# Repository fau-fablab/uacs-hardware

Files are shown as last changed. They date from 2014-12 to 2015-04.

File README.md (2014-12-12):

uacs
====

An universal access control system.

Usecase(s)
----------

* machine access control system:
  * monitor access to the machine
  * monitor the machine use time and whether the machine is in use or not
  * add the possibility to reserve machines
  * add a dead man's switch to the machine (force the user to interact with the uacs terminal every x minutes)

Features
--------

* [2.8" Touchscreen](../v2.0/pcb/datasheets/ILI9341.pdf)
* [ISO/IEC 14443A/MIFARE Reader/Writer (supports e.g. MIFARE Classic + DESFire)](../v2.0/pcb/datasheets/PN532-short.pdf)
* [ethernet-access](../v2.0/pcb/datasheets/W5100.pdf)
* powered via 2.1mm DC-Jack (Voltage: 7-50V) or passive POE (power over ethernet)
* micro-sd-card reader to store data (lcd-background images, caching of authorized rfid cards, ..)
* multiple IOs (I²C, UART, SPI, digital/analog pins e.g. to control relais or get sensor values)
* (piezo-)speaker for audio feedback
* real time clock

Remark
------

Development is still in progress, this is not a final version!<br />
If you want to contribute, take a look at the [wiki](https://github.com/fau-fablab/uacs/wiki/Contribution).

PCB
---

The terminal is built from two stacked pcbs in order to save space.<br />
Eagle Layout files and datasheets of used components can be found under [/pcb](../v2.0/pcb).

Firmware
--------

The firmware is written in arduino (c/c++) since the pcb is arduino mega compatible.<br />
The backend is (not yet ;)) written in Python.<br />
All code can be found under [/firmware](../v2.0/firmware).

License
-------

<br />This work is licensed under a <a rel="license" href="http://creativecommons.org/licenses/by-sa/4.0/">Creative Commons Attribution-ShareAlike 4.0 International License</a>.

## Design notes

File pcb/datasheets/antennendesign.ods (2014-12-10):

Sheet: Sheet1
Messen:
Lant = | 1.2 | uH | Q = | 35
Rant = | 1.6 | Ohm | Rges = | 2.92 | Rext = | 0.7 | Ohm
C1a = C1b = | 28 | pF |  | 200
C2a = C2b = | 202

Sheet: Sheet2
Messen:
L = | 1.25 | uH
R = | 2.4 | uH
La = Lb = | 0.625 | uH | Q = | 35
Rcoil = | 1.2 | Ohm | RL = | 3.04 |  | Rext = | 0.3 | Ohm
Xc1 = | 658 | Ohm |  | a | +jb
C1a = C1b = | 18 | pF | Z = | 200 | 0 | Xl = | 53.2499954783
Xc2 = | 58 | Ohm | w = | 85.20 | 1/us
C2a = C2b = | 204.0 | pF
 |  |  |  |  | a = | 15.7706926779
 |  |  |  |  |  | 53.5714240225
 |  |  |  |  | Nenner = | 19.8669443621

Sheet: Directly matched antenna
 | Directly matched antenna design |  |  |  |  |  | 06.11.2001 RBt
Input:
L = | 0.63 | uH | Q = | 22 |  | Z = Zant = | 700 | Ohm | Input
R = | 3.77 | Ohm
La = Lb = | 0.315 | uH | RL = | 2.44 |  |  |  |  | Result
Rcoil = | 1.885 | Ohm | RL/2 = | 1.22 | Ohm
Result:
C2a = C2b = | 419.9 | pF |  |  |  | Rext = | -0.67 | Ohm
C1a = C1b = | 40.4 | pF

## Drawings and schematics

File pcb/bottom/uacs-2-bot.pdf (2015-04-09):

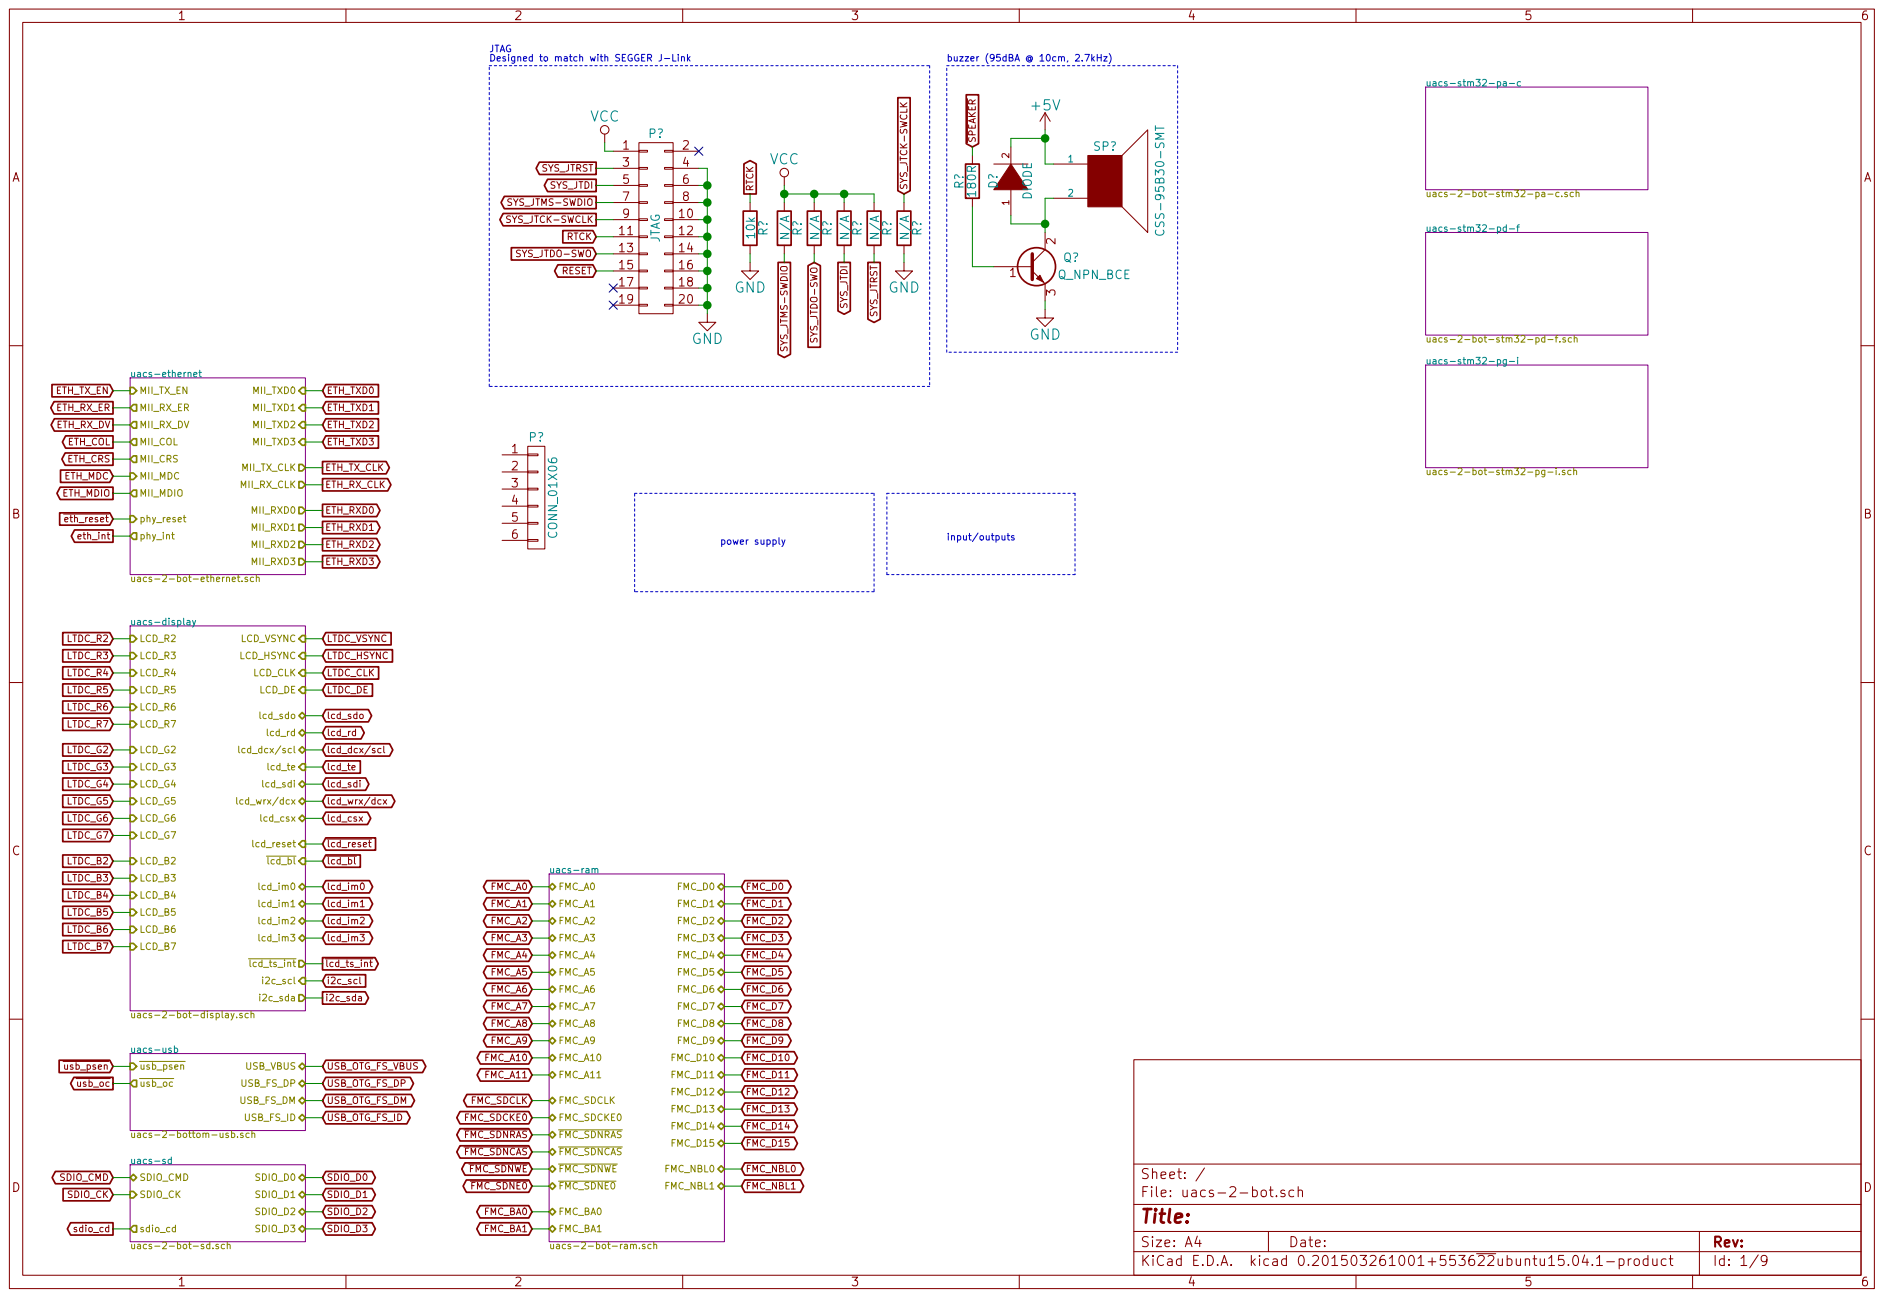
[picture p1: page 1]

uacs-stm32-pa-c uacs-2-bot-stm32-pa-c.sch

uacs-stm32-pd-f uacs-2-bot-stm32-pd-f.sch

uacs-stm32-pg-i uacs-2-bot-stm32-pg-i.sch

uacs-2-bottom-usb.sch

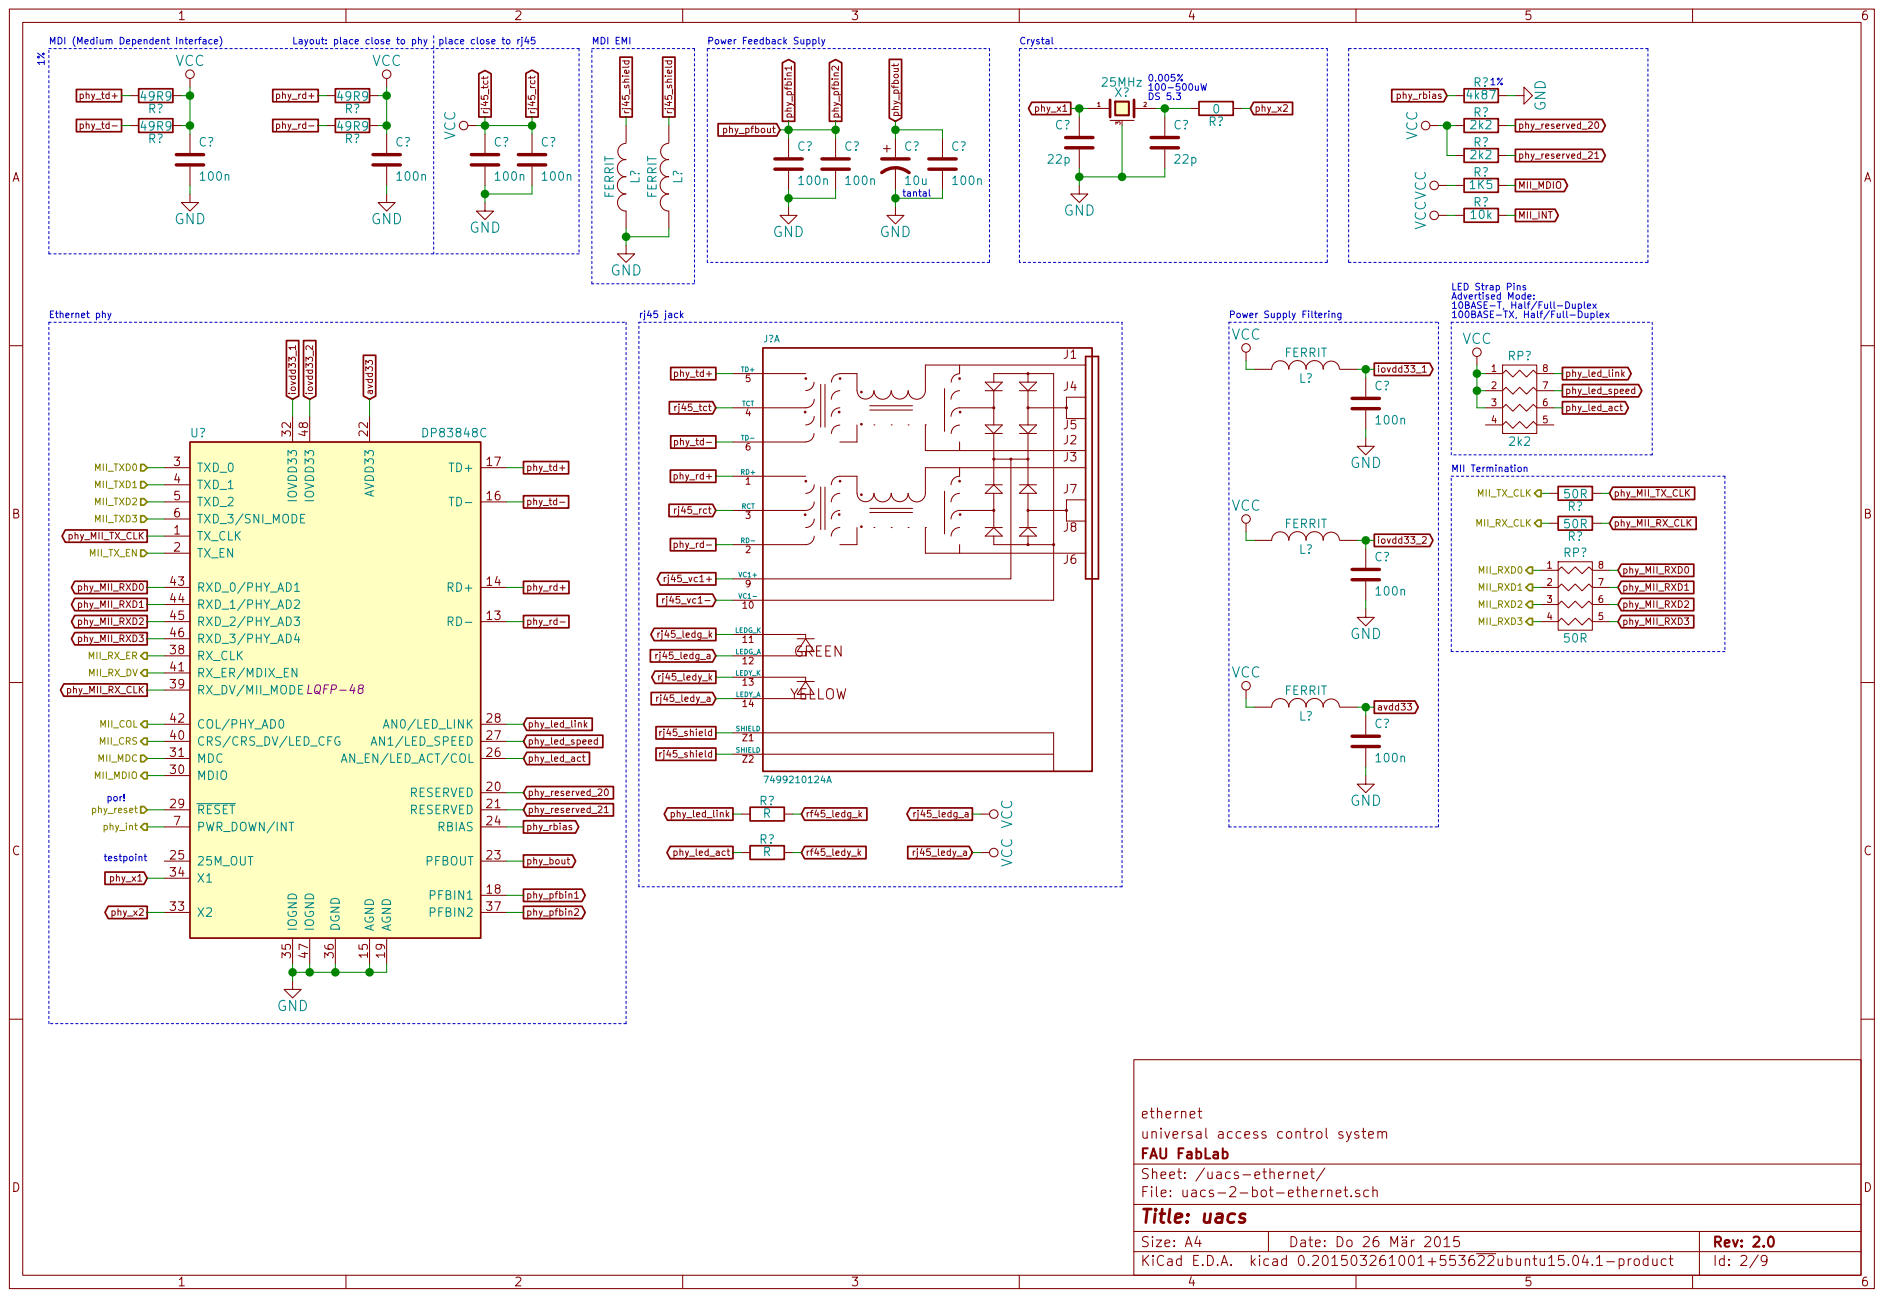
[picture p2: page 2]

LED Strap Pins Advertised Mode: 10BASE-T, Half/Full-Duplex 100BASE-TX, Half/Full-Duplex VCC VCC

ethernet
universal access control system
File: uacs-2-bot-ethernet.sch Sheet: /uacs-ethernet/ FAU FabLab

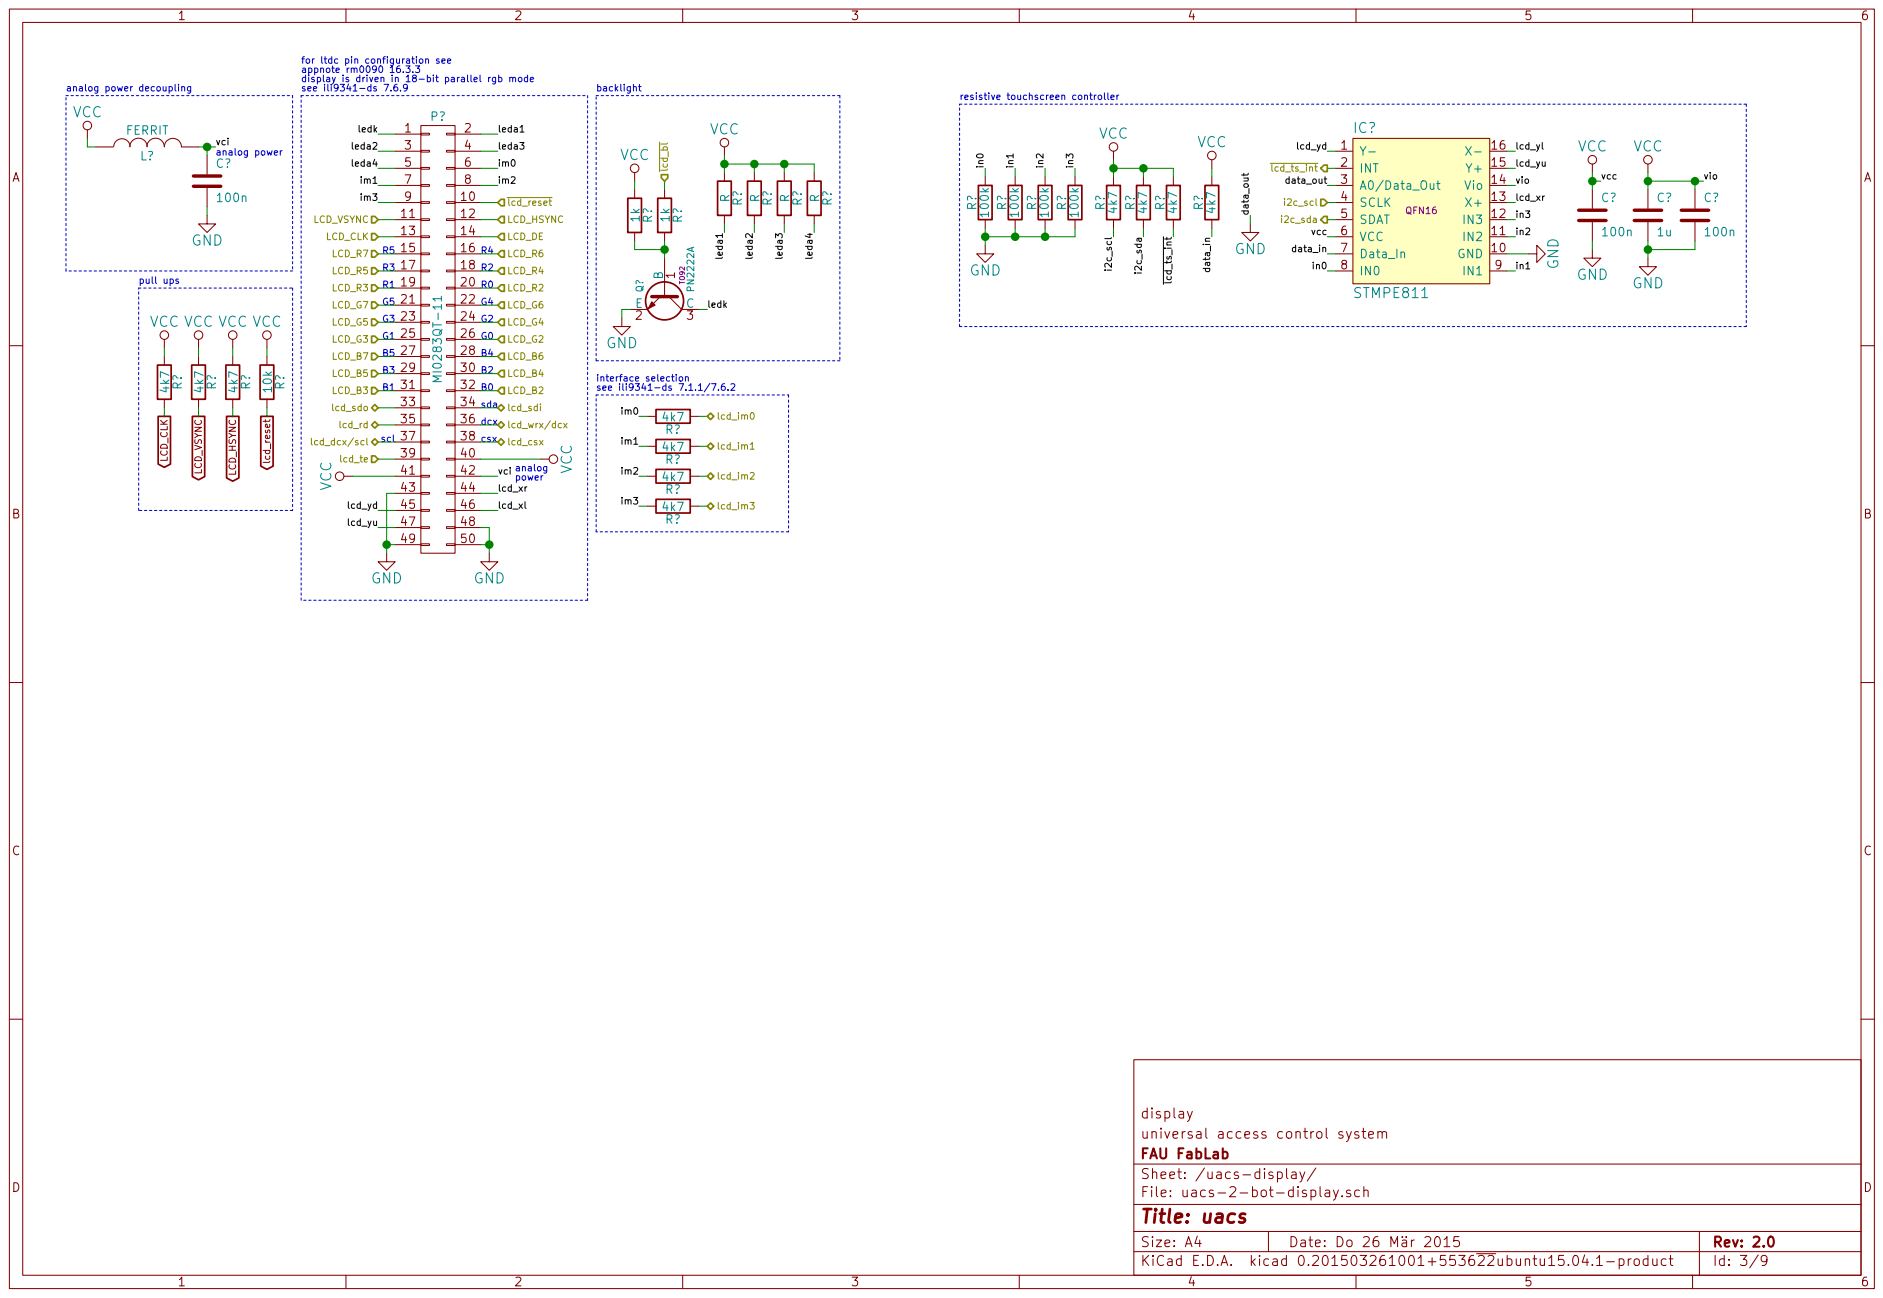
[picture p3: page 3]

for ltdc pin configuration see
appnote rm0090 16.3.3
display is driven in 18-bit parallel rgb mode

analog power pull ups analog power decoupling
100n VCC

display
universal access control system
Sheet: /uacs-display/ FAU FabLab

File: uacs-2-bot-display.sch
Id: 3/9 Title: uacs

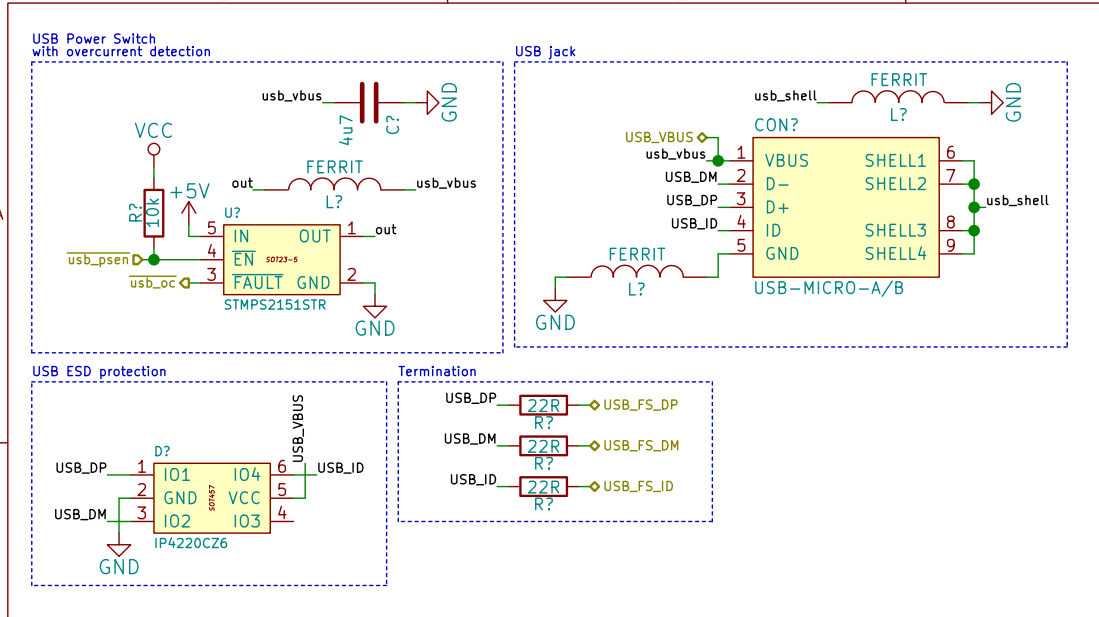
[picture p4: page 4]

Id: 4/9 Title: File: uacs-2-bottom-usb.sch Sheet: /uacs-usb/

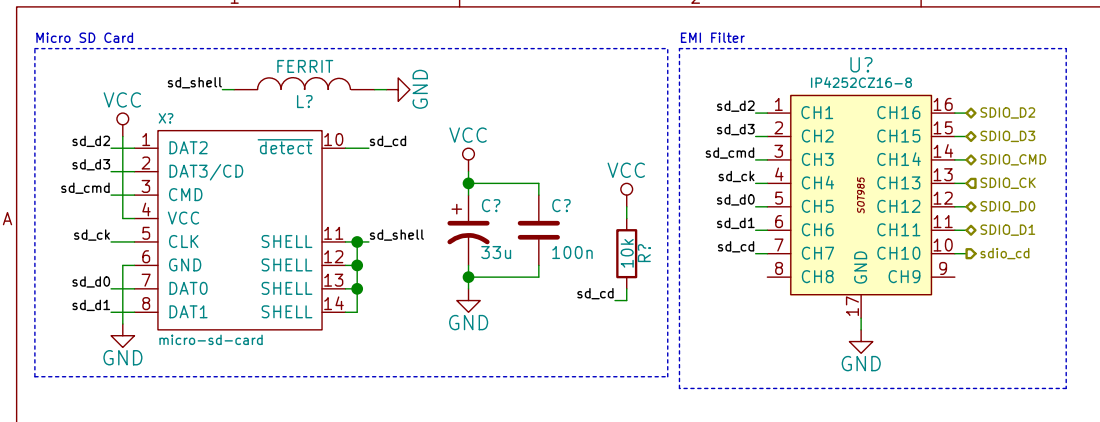
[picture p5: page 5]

Id: 5/9 Title: File: uacs-2-bot-sd.sch Sheet: /uacs-sd/

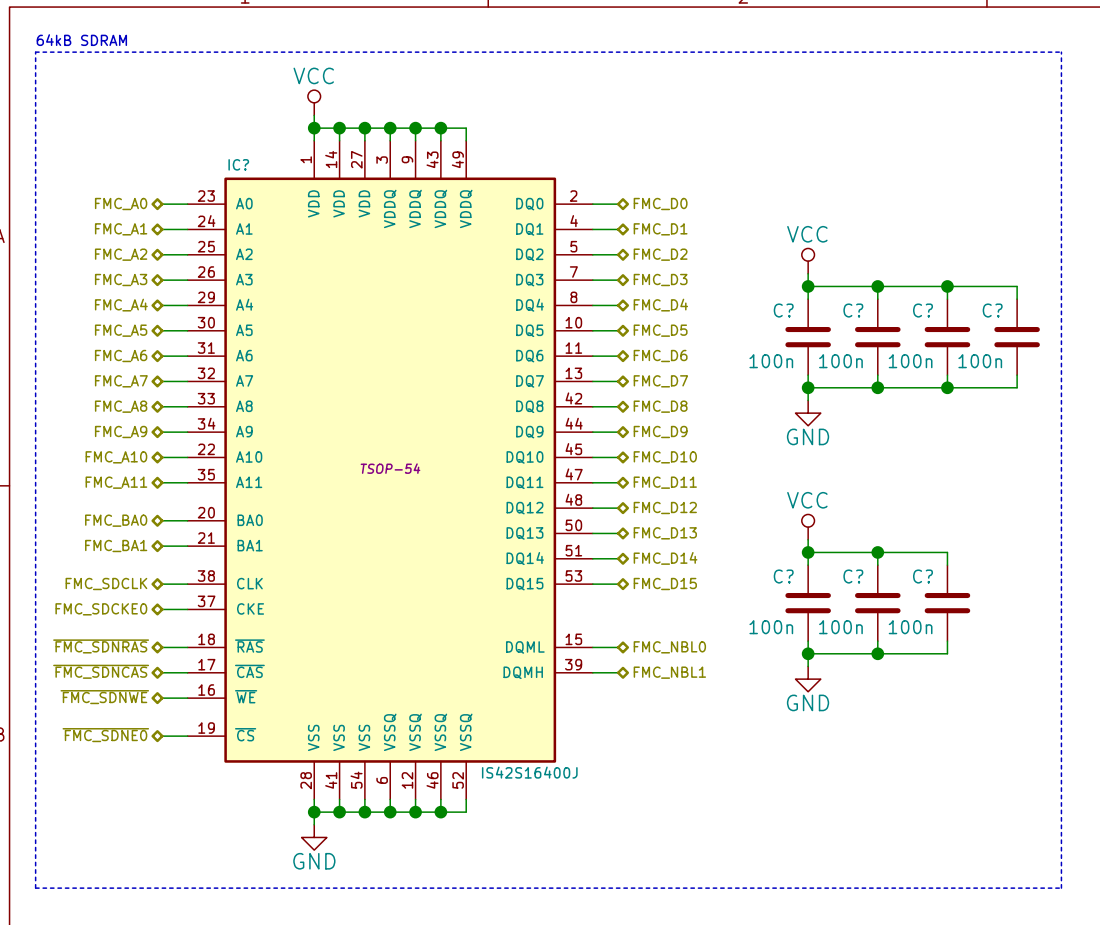
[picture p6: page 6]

9 DQ5 10 BA0 20 A5 30 DQ13 50 DQ6 11 BA1 21 A6 31 VSS 41 DQ14 51 VSSQ 12 A10 22 A7 32 DQ8 42 VSSQ 52 DQ7 13 A0 23 A8 33 VDDQ 43 DQ15 53 VDD 14 A1 24 A9 34 DQ9 44 VSS 54 DQML 15 A2 25 A11 35 DQ10 45 WE 16 A3 26 VSSQ 46 CAS 17 VDD 27 CKE 37 DQ11 47 RAS 18 VSS 28 CLK 38 DQ12 48 CS 19 A4 29 DQMH 39 VDDQ

1 DQ0 2 VDDQ
Id: 6/9 Title: File: uacs-2-bot-ram.sch Sheet: /uacs-ram/ VDD

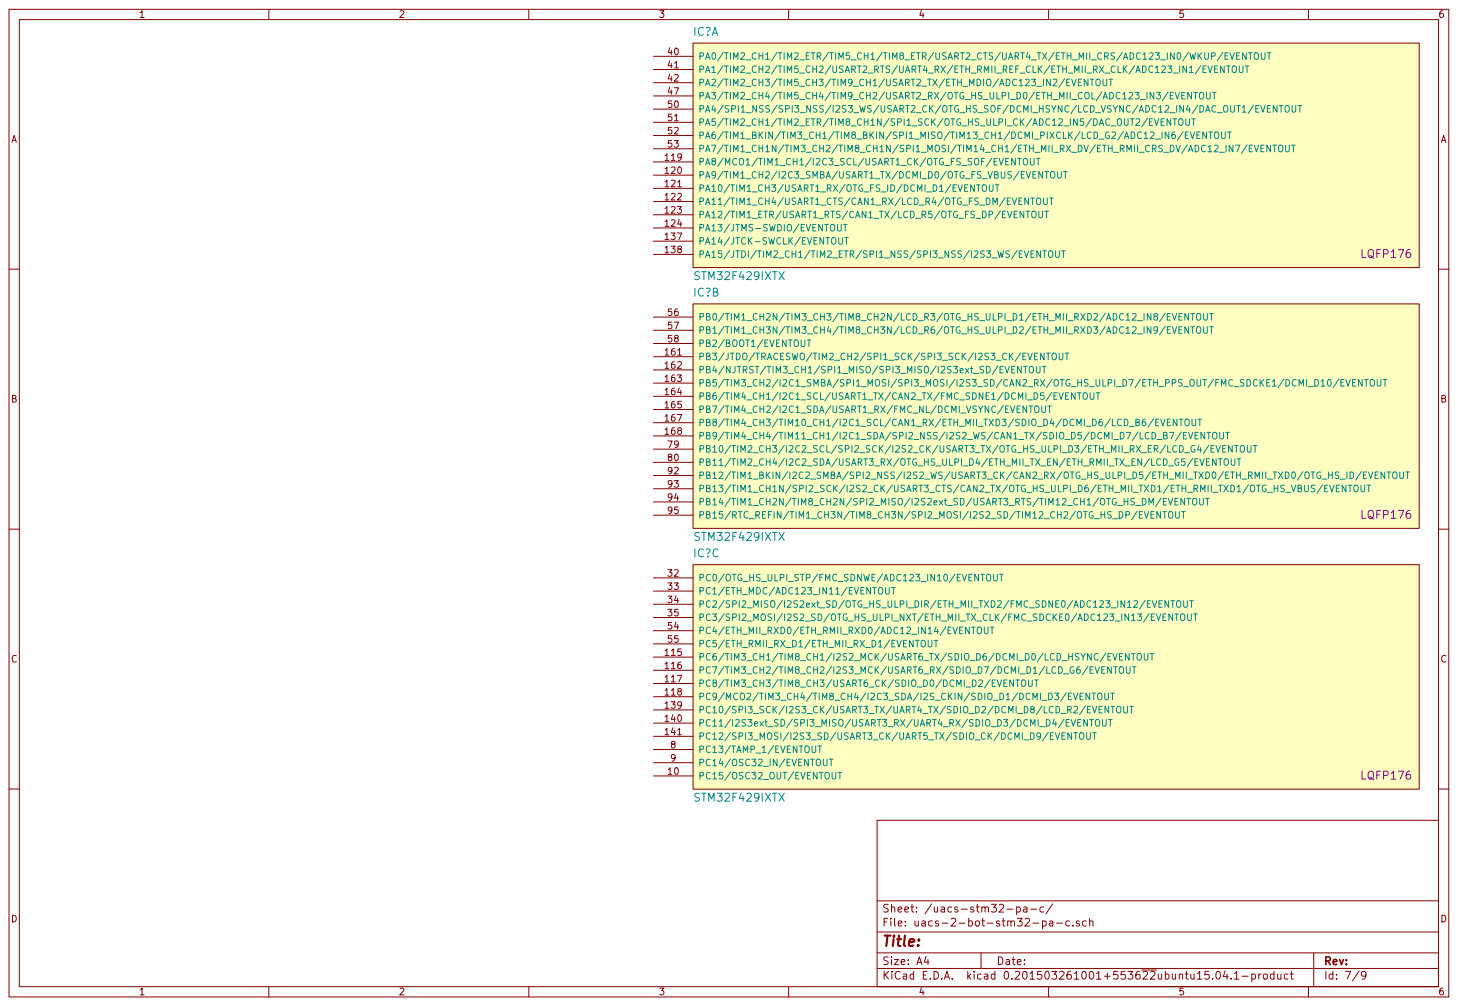
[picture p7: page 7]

Sheet: /uacs-stm32-pa-c/
File: uacs-2-bot-stm32-pa-c.sch
Id: 7/9 Title:

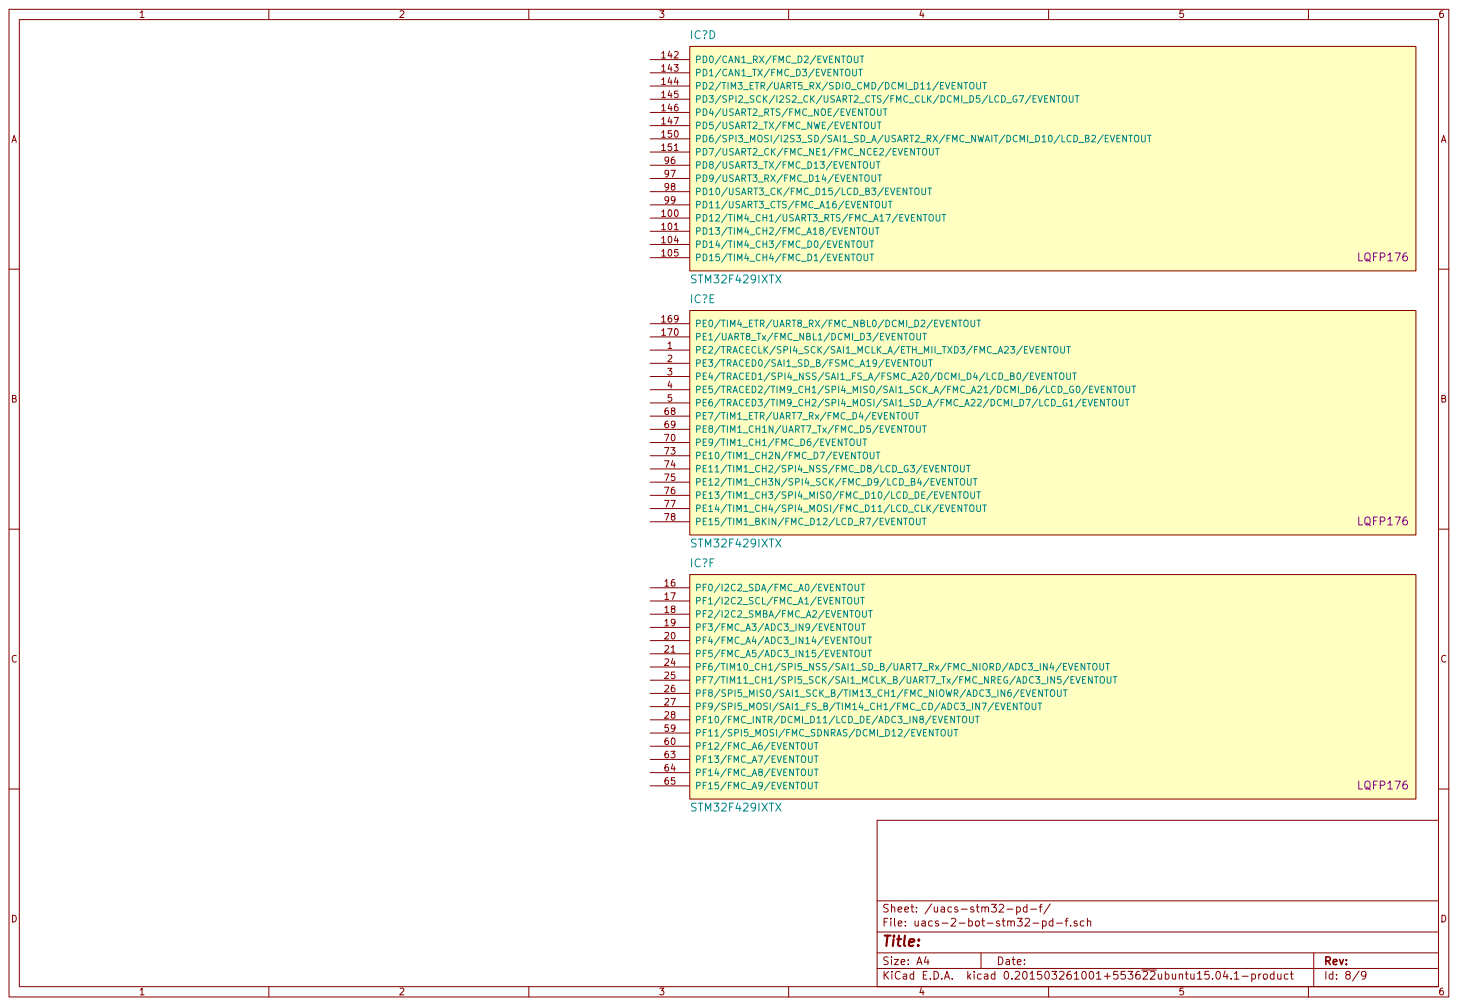
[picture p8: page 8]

Sheet: /uacs-stm32-pd-f/
File: uacs-2-bot-stm32-pd-f.sch
Id: 8/9 Title:

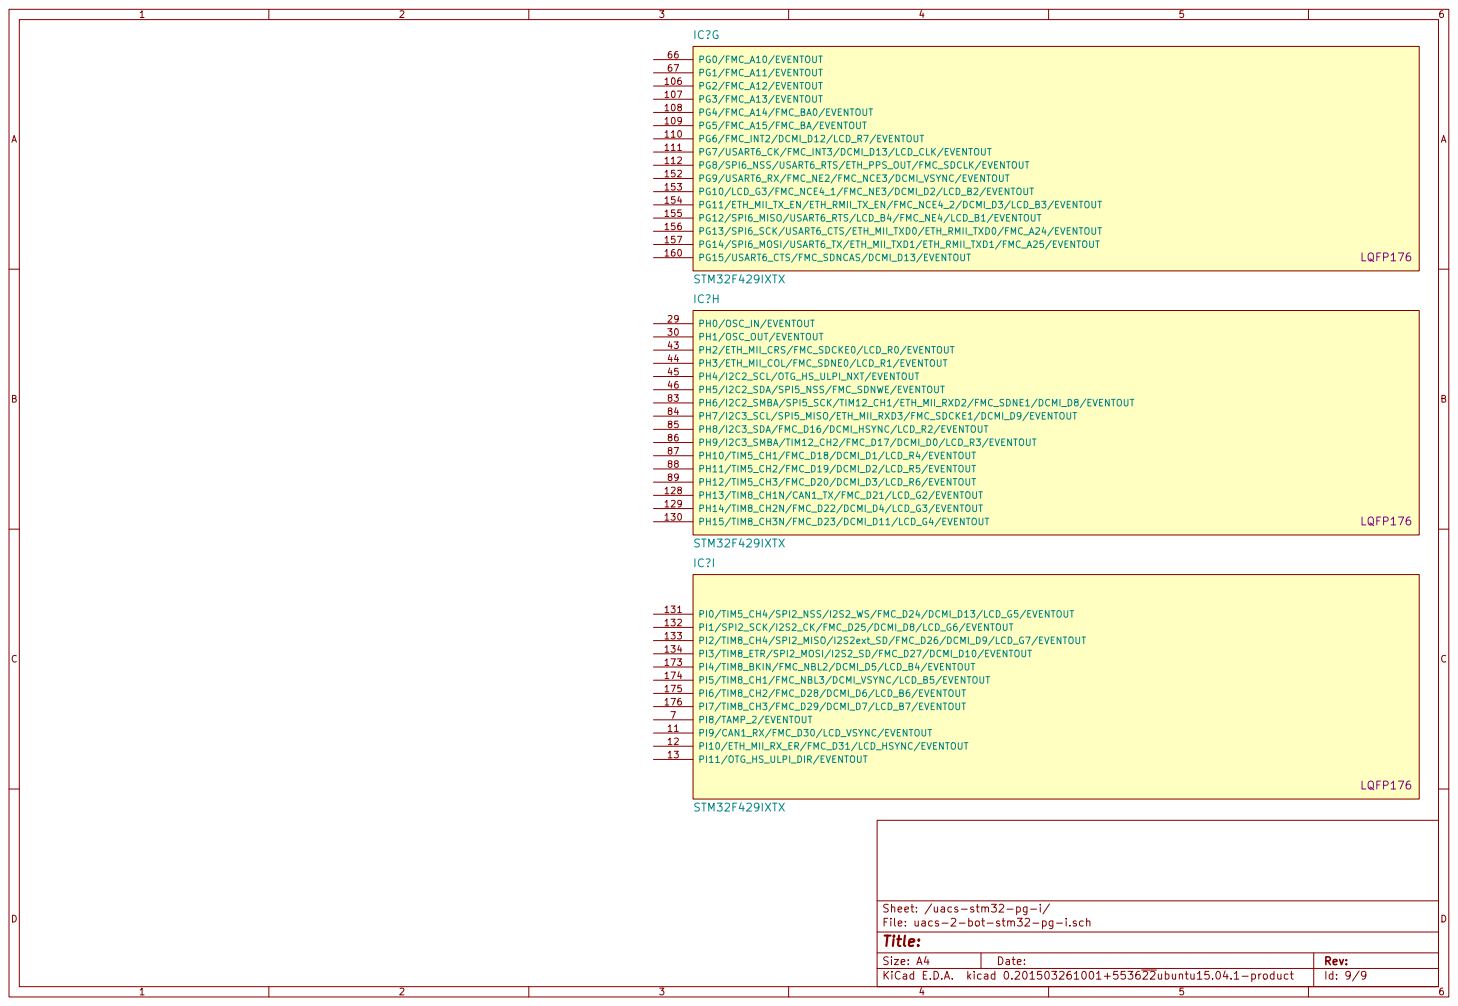
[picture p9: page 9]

Sheet: /uacs-stm32-pg-i/
File: uacs-2-bot-stm32-pg-i.sch
Id: 9/9 Title:

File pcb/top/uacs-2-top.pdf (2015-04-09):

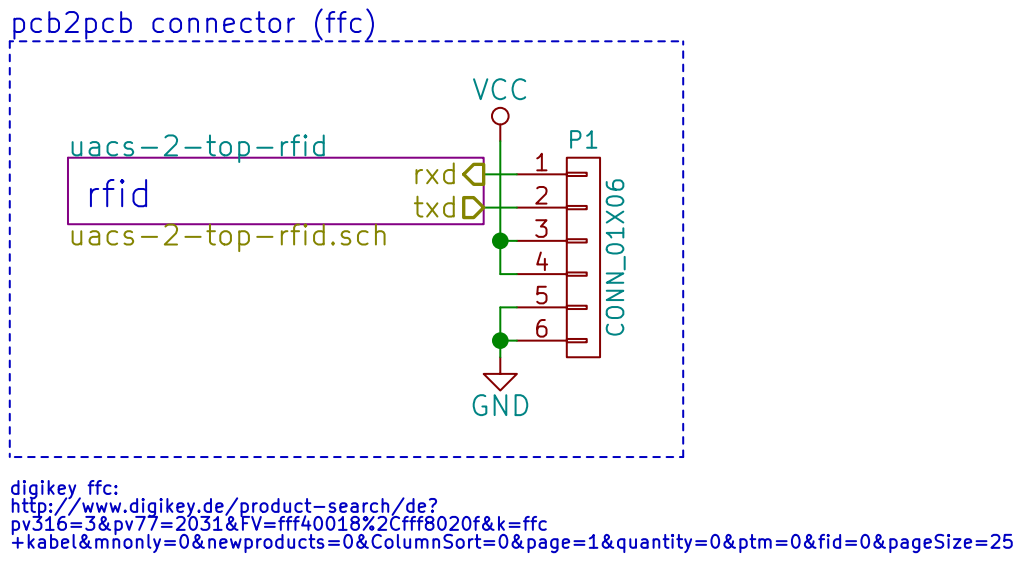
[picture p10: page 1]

pcb2pcb connector (ffc) digikey ffc: http://www.digikey.de/product-search/de?

pv316=3&pv77=2031&FV=fff40018%2Cfff8020f&k=ffc +kabel&mnonly=0&newproducts=0&ColumnSort=0&page=1&quantity=0&ptm=0&fid=0&pageSize=25 uacs-2-top-rfid
rfid
uacs-2-top-rfid.sch

top pcb
universal access control system
File: uacs-2-top.sch Sheet: / FAU FabLab

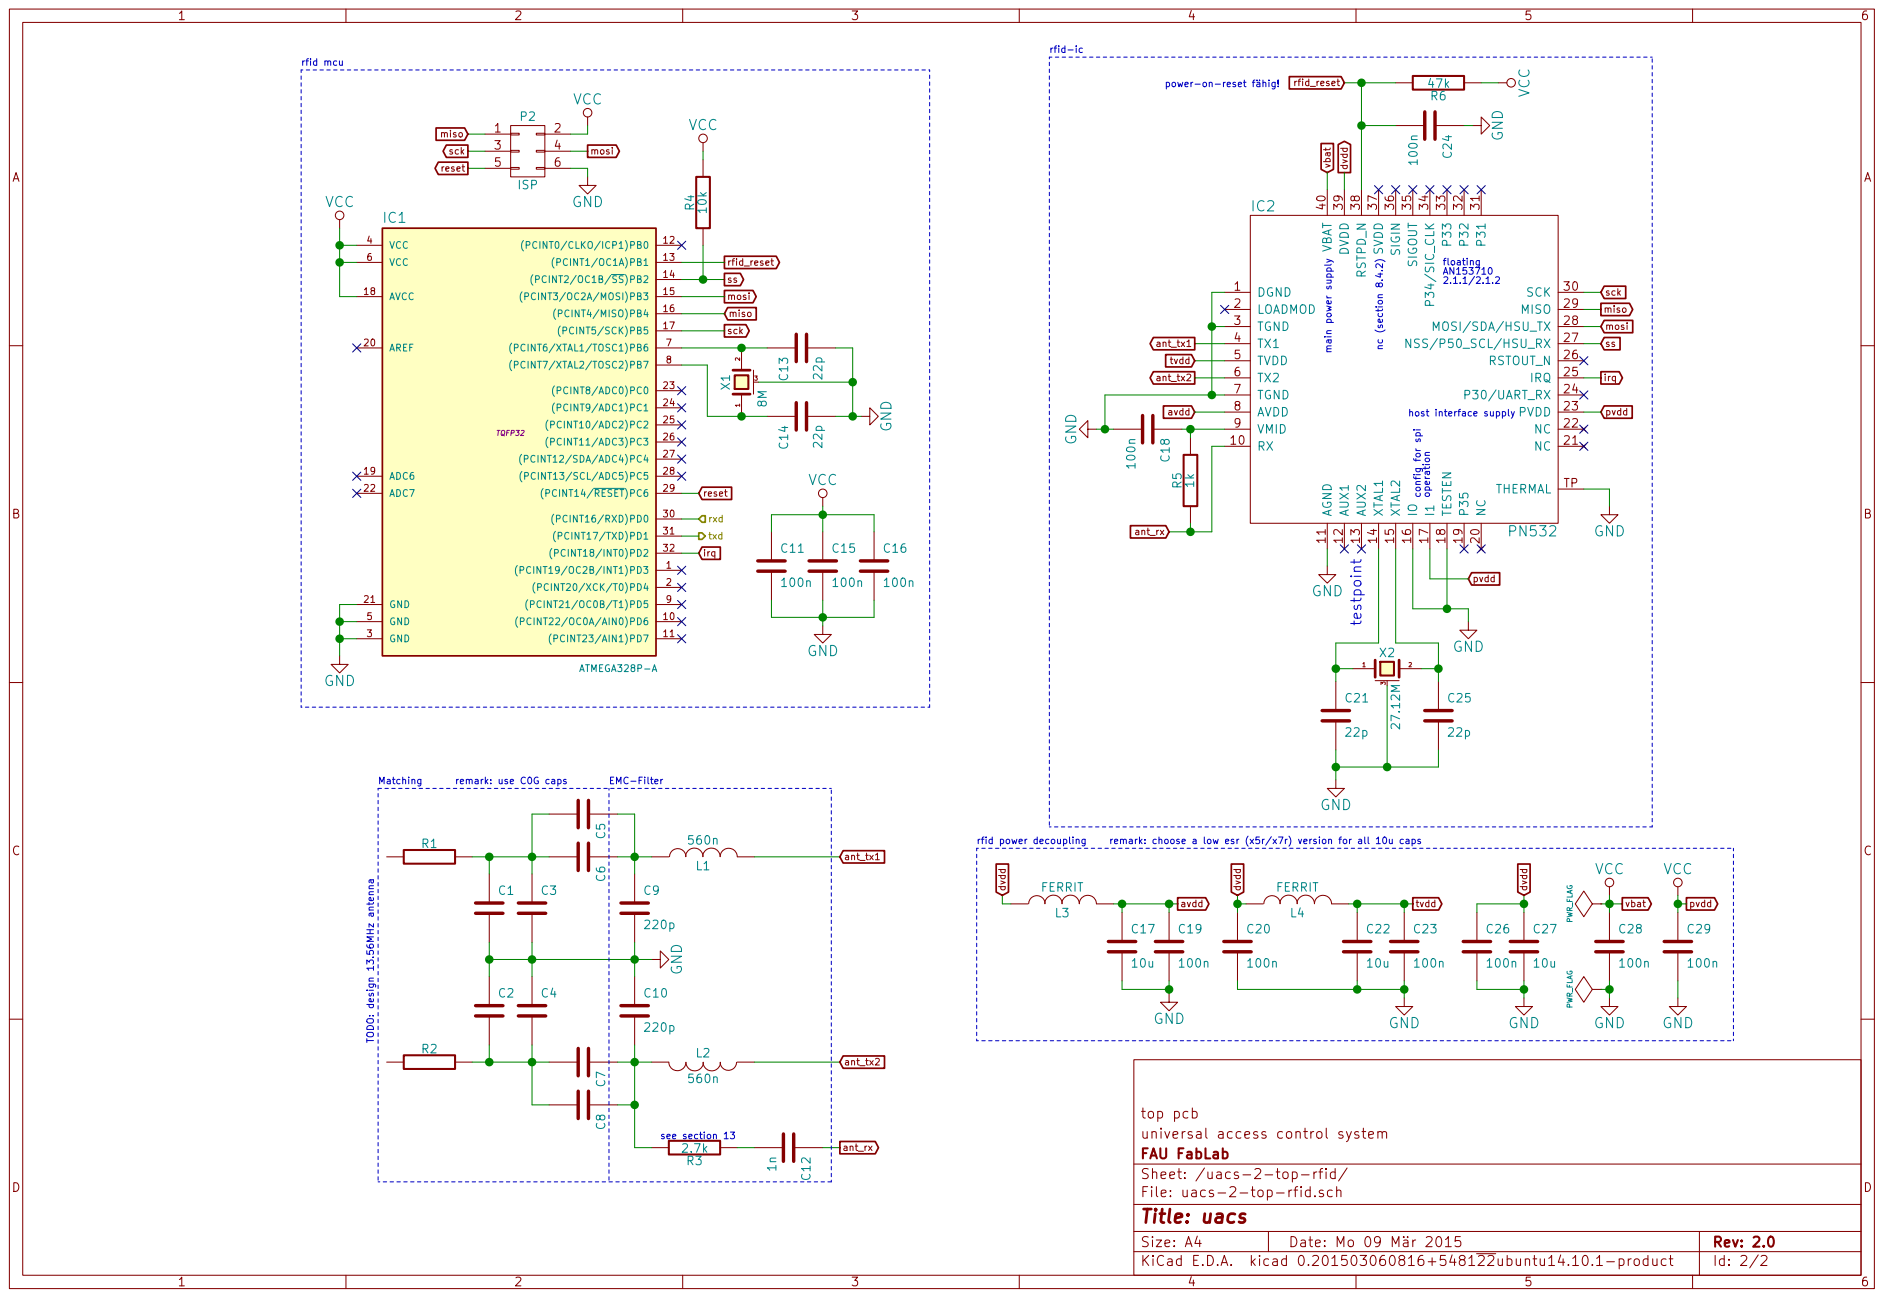
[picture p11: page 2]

top pcb
universal access control system
Sheet: /uacs-2-top-rfid/ FAU FabLab

File: uacs-2-top-rfid.sch
Id: 2/2 Title: uacs

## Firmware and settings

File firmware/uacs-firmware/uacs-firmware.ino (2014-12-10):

#include <MFRC522.h>
#include <Queue.h>
#include "Adafruit_ILI9341.h"
#include "Adafruit_GFX.h"
#include "Ethernet.h"
#include "ADS7846.h"
#include "SPI.h"

#define TFT_CS 43
#define TFT_DC 5
#define RFID_SS 45

byte mac[] = { 0xDE, 0xAD, 0xBE, 0xEF, 0xFE, 0xED };
unsigned int blBrightness = 255;
unsigned int newBlBrightness = 255;

Adafruit_ILI9341 tft = Adafruit_ILI9341(TFT_CS, TFT_DC);
EthernetClient client;
ADS7846 touch;
MFRC522 mfrc522(RFID_SS, 7);
Queue blQueue;

void setup(){
  //rfid-led
  pinMode(48, OUTPUT);
  digitalWrite(48, HIGH);

  //speaker
  pinMode(13, OUTPUT);
  
  //display bl
  pinMode(44, OUTPUT);
  
  //peninterrupt
  pinMode(19, INPUT);
  
  //mfrc522.PCD_Init();

  //perform self test
  if(!selfTest()){
    while(1){
      ;
    }
  } else {
    //audio feedback
    analogWrite(13, 200);
    delay(200);
    analogWrite(13, 0);
  }
  
  delay(200);
  
  tft.fillScreen(ILI9341_RED);
  tft.setCursor(16,16);
  tft.setTextColor(ILI9341_WHITE);
  tft.setTextSize(5);
  tft.println("LOCKED!");
  tft.println("");
  tft.println("");
  tft.setTextSize(2);
  tft.println(" Swipe Card to Login.");
  
  attachInterrupt(4, touchInterrupt, FALLING);
  
  newBlBrightness = 20;
  blQueue.scheduleFunction(dimBl, "blQueue", 30000, 0);
}

void loop(){
  blQueue.Run(millis());
}

bool selfTest(){
	//store start time
	unsigned long start = micros();

	//init lcd
	tft.begin();
	tft.setRotation(3);
	//test lcd
	if(tft.readcommand8(ILI9341_RDMODE) == 0x9C){
		tft.fillScreen(ILI9341_BLACK);
                analogWrite(44, blBrightness);
		tft.setCursor(0,0);
		tft.setTextColor(ILI9341_WHITE);
		tft.setTextSize(1);
		tft.println("UACS - Universal Access Control System");
		tft.println("Firmware Rev1.0");
		tft.println("--------------------------------------");
		tft.print("[");
		tft.print(micros() - start);
		tft.println("] ILI9341: Display OK, Power Mode: 0x9C");
	} else {
		return false;
	}

	//init ethernet
	if(Ethernet.begin(mac)){
		tft.print("[");
		tft.print(micros() - start);
		tft.print("] W5100: Ethernet OK, IP: ");
		tft.println(Ethernet.localIP());
	} else {
		tft.print("[");
		tft.print(micros() - start);
		tft.println("] W5100: Ethernet FAIL");
	}

	//init touch
	touch.begin();
	touch.service();
	tft.print("[");
	tft.print(micros() - start);
	tft.print("] TSC2046: Current pressure: ");
	tft.println(touch.getPressure());

	//TODO: init rfid
	tft.print("[");
	tft.print(micros() - start);
	tft.println("] MFRC531: RFID OK ");

	//TODO: init sd-card
	tft.print("[");
	tft.print(micros() - start);
	tft.println("] SD: Card OK ");

	return true;
}

int dimBl(unsigned long now){
  while(blBrightness != newBlBrightness){
    analogWrite(44, blBrightness);
    if(blBrightness > newBlBrightness){
      blBrightness--;
    } else {
      blBrightness++;
    }
    delay(2);
  }
}

void touchInterrupt(){
  newBlBrightness = 255;
  dimBl(0);
  newBlBrightness = 20;
  blQueue.scheduleRemoveFunction("blQueue");
  blQueue.scheduleFunction(dimBl, "blQueue", 30000, 0);
}

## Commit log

2014-12-10 initial commit v2.0
    [uacs-bom.ods, uacs-bottom.brd, uacs-bottom.sch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]
2015-04-09 move to kicad
    [uacs-2-bot-connectors.sch, uacs-2-bot-display.sch, uacs-2-bot-ethernet.sch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]
